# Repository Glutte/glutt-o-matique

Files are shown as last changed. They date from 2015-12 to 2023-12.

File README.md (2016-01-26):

Glutt-o-matique
===============

La nouvelle logique de la Glutte voit le jour ici.

On va utiliser un stm32f4-discovery. La collaboration
est gérée à l'aide d'un
[Trello](https://trello.com/b/NSvh8v81),
qui sert aussi d'aide-mémoire.

[La Glutte](http://www.glutte.ch)

L'essence de la glutt-o-matique
-------------------------------

Notre but  
est que la glutte  
fasse des tût-tûts.

Pour faire écho  
des beaux QSO  
depuis là-haut.

Donner comme retour  
entre chaque tour  
une lettre nuit et jour

Économiser l'energie  
pour la longue vie  
de la batterie.

Tout en annoncant  
le beau temps  
régulièrement.

Structure
---------

La machine d'états

Le PCB de prototype.

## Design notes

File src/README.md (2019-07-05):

Structure des dossiers source
=============================

- *bsp* pilotes et lib essentielle pour le STM32F4
- *common* sources utilisées dans la glutt-o-logique et le simulateur
- *FreeRTOS* sources de l'OS FreeRTOS pour le STM32F4
- *FreeRTOS-Sim-master* sources de la variante de FreeRTOS pour le simulateur
- *glutt-o-logique* code applicatif spécifique au STM32F4
- *simulator* code applicatif spécifique au simulateur y.c. interface graphique
- *temperature* code d'exemple, pour illustrer l'utilisation des entrées analogiques du STM32

Compiler le Simulateur
======================

Le simulateur de glutt-o-matique 3000 permet de tester le fonctionnement de la
logique sur un PC sans matériel spécial. Il faut un PC sous linux avec les librairies
X11, GL, GLU et pulseaudio, et faire

    cd simulator
    make
    ./FreeRTOS-Sim

Compiler le projet STM32
========================

Il faut un compilateur pour arm-none-eabi-, qui doit être dans le $PATH. Il
faut openocd pour FLASHer le STM32F4-DISCOVERY.

    cd glutt-o-logique
    make
    make deploy

Debug avec OpenOCD et GDB
=========================

    openocd -f /usr/share/openocd/scripts/board/stm32f4discovery.cfg  -c init -c reset

    arm-none-eabi-gdb bin/outp.elf
    target extended-remote localhost:3333
    monitor reset halt
    load
    continue

Debug simulateur avec GDB
=========================

    handle SIGUSR1 nostop noignore noprint
    handle SIG34 nostop noignore noprint

Analyse statique avec clang
===========================

Dans le simulateur scan-build tout seul fonctionne, mais dans glutt-o-logique/ il faut

    scan-build --use-cc=arm-none-eabi-gcc --analyzer-target=arm-none-eabi make ARCH=arm CROSS_COMPILE=arm-none-eabi-

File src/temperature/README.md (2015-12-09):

An example program that tries to read the
current temperature on the STM32F4DISCOVERY.

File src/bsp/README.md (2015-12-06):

This folder contains all files necessary to compile for the
STM32F4DISCOVERY board

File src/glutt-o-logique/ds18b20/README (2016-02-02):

This folder contains a library to access Dallas 1-wire temperature sensors.

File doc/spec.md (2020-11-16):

##Généralités

En mode secours, la glutt-o-matique doit être entièrement désactivée. Cela est
garanti en connectant le signal `SECOURS` sur l'entrée `RESET` du
microcontrôleur.

##Limites de tension pour QRP

Avec hysterèse:

 - en dessous de 12V5, passer en QRP
 - en dessus de 13V, passer en QRO

##Lettres CW

 * K : tout va bien (priorité 0)
 * G : relais en petite puissance (priorité 2)
 * U : RX trop haut en référence à 145'125 MHz (priorité 3)
 * D : RX trop bas 145'125 MHz (priorité 3)
 * S : mode SSTV (sans filtre 1725 Hz, priorité 1)
 * R : ROS sur antenne (priorité 4)

##Première phase : ouverture du relais
 * 1750 Hz pendant 200 ms, puis après relâchement de la porteuse :
 * TX ON, -> pause de 200ms, puis :
 * K,G,U,D,R (selon la situation du moment present du relais)

##Ensuite :

 * Pas de QSO, -> TX OFF après 6 s -> impossible de réentendre K, G, U, D, R pendant 15 s. Réouverture possible cependant du relais, pendant ce laps de temps de 15 s.
 * QSO -> le relais compte le temps d’un utilisateur, si plus de 5 min avec le même utilisateur, alors anti-bavard -> modulation OFF, et texte CW : HI HI, puis stop relais pendant 10 s, réouverture impossible avant 10 s
 * QSO normal de moins de 5 min. -> si plus d’action de PTT, fermeture du relais après 5 s, sans texte CW, puis idem :
 * QSO normal dépassant 5 min ->  texte CW : *73*, puis fermeture.
 * QSO normal dépassant 10 min ->  texte CW : *HB9G*, puis fermeture.
 * QSO normal dépassant 15 min ou plus -> texte CW au hasard, soit *HB9G JN36BG* ou *HB9G 1628 M*, puis fermeture

##Relais stand-by :
 * Pendant toutes les minutes que le relais n’est pas utilisé, après 20 minutes de silence consécutif, il TX une balise, au hasard, soit : *HB9G*, ou *HB9G JN36BK*, ou *HB9G 1628 M*, ou *HB9G JN36BK 1628 M*. Pendant ces balises, si un utilisateur utilise son PTT, il peut utiliser le relais comme si il avait fait un 1750 Hz, le relais réagit comme une ouverture normale.
 * Timer de balise : Commence à compter lors de l'arrêt du relais. Si qso, arrêt de timer avec mémoire du temps écoulé, puis reprise du comptage dès la fin du qso. Si qso plus long que 10 min. -> timer RAZ. Si timer = 20 min TX balise, puis RAZ
 * Si le relais en QRP ou ROS, plus aucune de ces balise sont en fonction
 * Une fois entrée en mode ROS, seul une coupure de courant ou un passage en SECOURS peut faire passer en mode normal.

##Toutes les heures paires :

Le relais, seulement s'il n'y a pas de QSO en cours, (sinon il attend la fin du QSO), dès qu’il a la possibilité, il prend la main sur toutes autres activités possible, (modulation off, et 1750Hz) puis il TX une balise.

A partir d'octobre 2020:

*HB9G JN36BK U 13V5  1650 AH + T 12  73*

Tendance: + - ou = selon l'évolution de la capacité en Ah. T par pas de 1 degré C. *73* si éolienne dans le vent, *SK*
si repliée.

En QRP, *HB9G U 12V5  1010 AH  T 12  73*

Jusqu'en octobre 2020:

*HB9G JN36BK 1628 M U 13V5* (un pas de 0,5V est suffisant) puis la tendance à la charge ou décharge ou égale (representés par +/-/=), *T* (température) par pas de 2 degrés, puis *73* si la queue de l’éolienne est dans le vent, ou *SK* si elle est repliée.

Ou, si le relais en en QRP, ou ROS, alors :

*HB9G U 12V5 73* ou *SK*

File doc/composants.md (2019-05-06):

Quelques références de composants utilisées pour la glutt-o-matique

 - STM32DISCOVERY | ST Microelectronics |
 - Perfboard | Twin Industries 8100-45 |
 - Connecteur 12V | LEMO EGG.0B.302.CLL |
 - Connecteur DB25 filtré | FDB-25PTI2/1-LF |

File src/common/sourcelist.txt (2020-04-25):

GPIO/analog.c
GPIO/usart.c
GPIO/temperature.c
GPIO/batterycharge.c
GPS/gps.c
GPS/minmea.c
Core/common.c
Core/fsm.c
Core/stats.c
Core/main.c
Audio/cw.c
Audio/audio.c
Audio/audio_in.c
Audio/tone.c

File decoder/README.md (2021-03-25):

Introduction
------------

This folder contains a set of scripts that can be used to automatically decode the PSK125 beacon at 22:00

The `analyse_capture.grc` was designed with GNURadio 3.7, but later the python file was
manually ported to GNURadio 3.8, because the [MPSK receiver block was deprecated](https://github.com/gnuradio/gnuradio/issues/1083)

Dependencies
------------

* Python 3
* GNURadio 3.8
* An SDR device and a suitable I/Q capture tool

Principle of operation
----------------------

1. Capture I/Q data, in u8 format, at 20148ksps, centered on 145.700MHz, into a file called `iq.raw`
1. Demodulate FM and PSK using the GNURadio flowgraph `analyse_capture.grc`. It will write a file called `psk125.bit`
1. Run the `varidecode.py` script, which will read `psk125.bit` and write `psk125.txt` with decoded beacon data

Example for RTLSDR: `rtl_sdr -f 145700000 -n 204800000 iq.raw` will capture 100 seconds worth of IQ data.

References
----------

https://sdradventure.wordpress.com/2011/10/15/gnuradio-psk31-decoder-part-1/

https://sdradventure.wordpress.com/2011/10/15/gnuradio-psk31-decoder-part-2/

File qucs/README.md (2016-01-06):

Quelques simulations qucs pour la glutt-o-matique

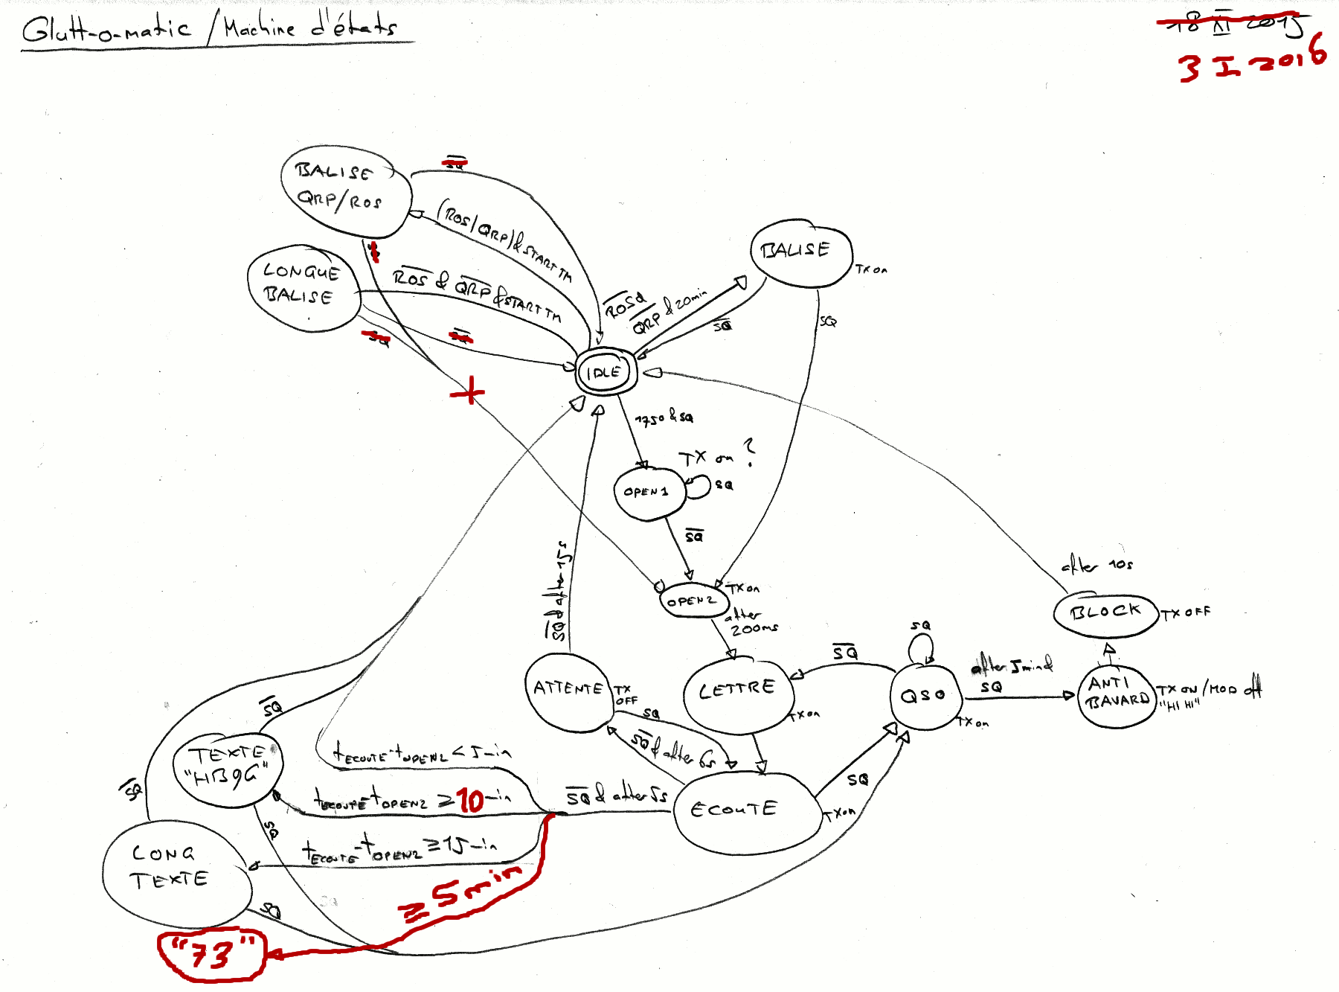
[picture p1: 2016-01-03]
doc/20160103-machine-etats.png

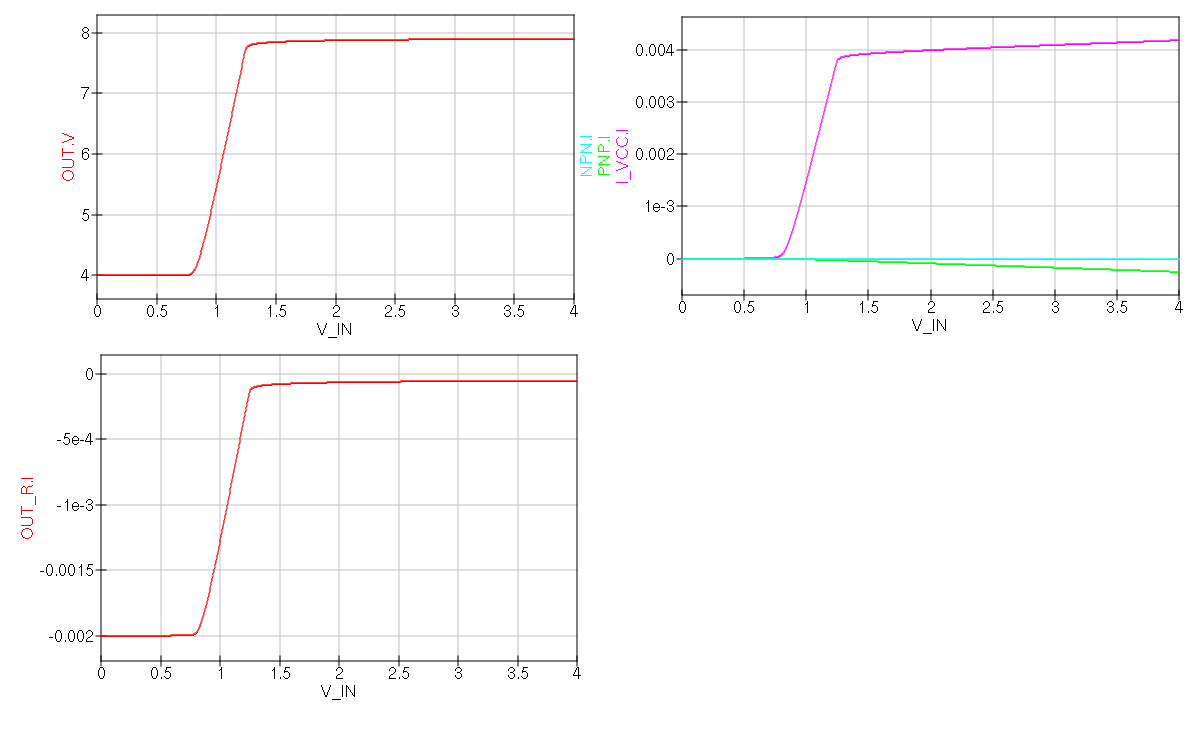
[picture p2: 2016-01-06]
qucs/levelshifter-graphs.png

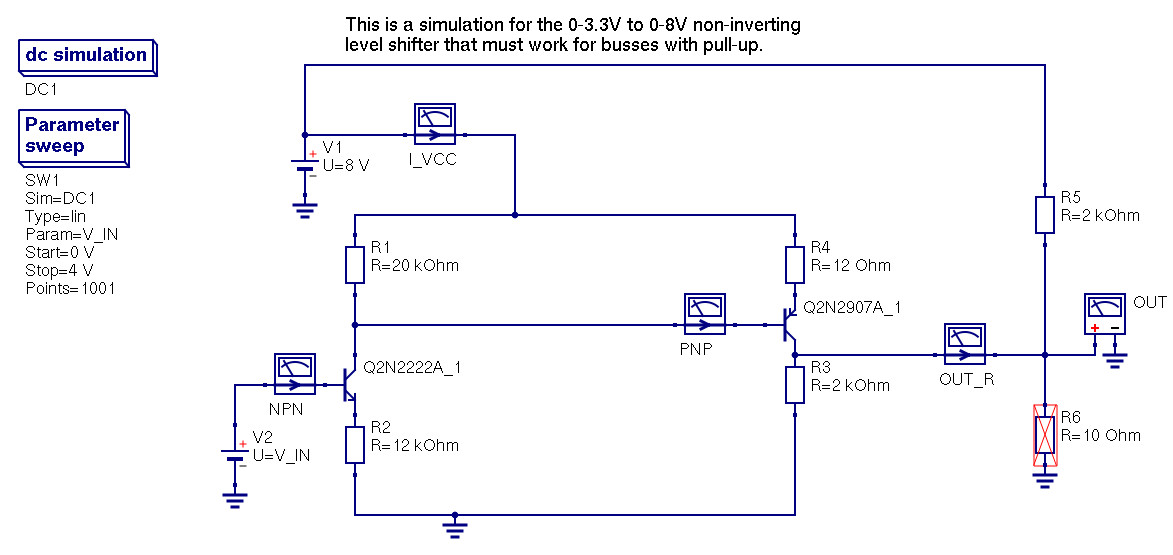
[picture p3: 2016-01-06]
qucs/levelshifter.png

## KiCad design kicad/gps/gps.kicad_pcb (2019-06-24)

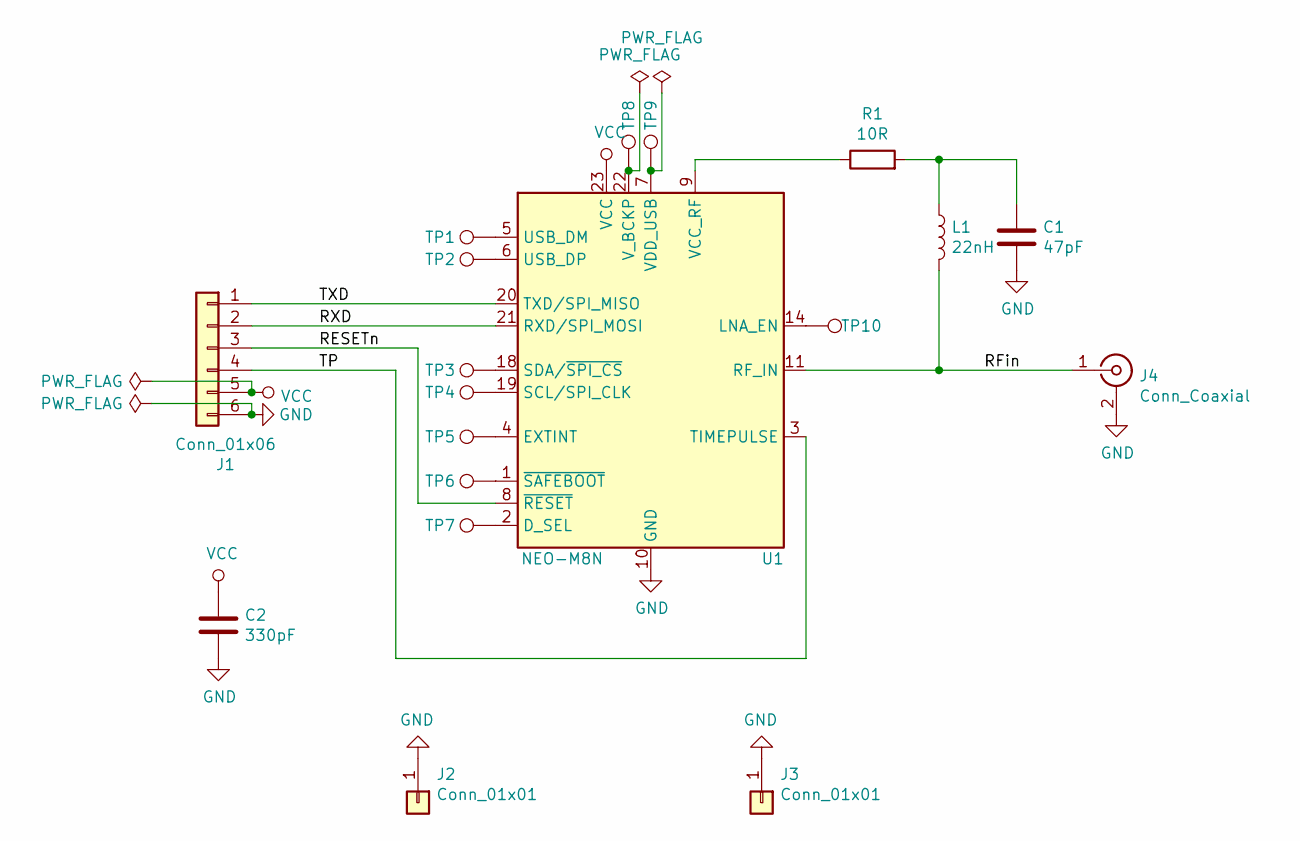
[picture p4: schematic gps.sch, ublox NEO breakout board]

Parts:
C1: 47pF; C_0603_1608Metric_Pad1.05x0.95mm_HandSolder
C2: 330pF; C_0805_2012Metric_Pad1.15x1.40mm_HandSolder
J1: Conn_01x06; PinHeader_1x06_P2.54mm_Vertical
J2, J3: Conn_01x01; PinHeader_1x01_P2.54mm_Vertical
J4: Conn_Coaxial; SMA_Samtec_SMA-J-P-H-ST-EM1_EdgeMount
L1: 22nH; L_0603_1608Metric_Pad1.05x0.95mm_HandSolder
R1: 10R; R_0603_1608Metric_Pad1.05x0.95mm_HandSolder
TP1: DM; TestPoint_Pad_1.0x1.0mm
TP2: DP; TestPoint_Pad_1.0x1.0mm
TP3: SDA; TestPoint_Pad_1.0x1.0mm
TP4: SCL; TestPoint_Pad_1.0x1.0mm
TP5: EXTINT; TestPoint_Pad_1.0x1.0mm
TP6: SB; TestPoint_Pad_1.0x1.0mm
TP7: DSEL; TestPoint_Pad_1.0x1.0mm
TP8: VBKP; TestPoint_Pad_1.0x1.0mm
TP9: VUSB; TestPoint_Pad_1.0x1.0mm
TP10: LNA; TestPoint_Pad_1.0x1.0mm
U1: NEO-M8N; ublox_NEO

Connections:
/RESETn: J1.3, U1.8 (~RESET)
/RFin: J4.1 (In), L1.2, U1.11 (RF_IN)
/RXD: J1.2, U1.21 (RXD/SPI_MOSI)
/TP: J1.4, U1.3 (TIMEPULSE)
/TXD: J1.1, U1.20 (TXD/SPI_MISO)
GND: C1.2, C2.2, J1.6, J2.1, J3.1, J4.2 (Ext), U1.10 (GND), U1.12 (GND), U1.13 (GND), U1.24 (GND)
unnamed: C1.1, L1.1, R1.2
unnamed: R1.1, U1.9 (VCC_RF)
unnamed: TP1.1, U1.5 (USB_DM)
unnamed: TP2.1, U1.6 (USB_DP)
unnamed: TP3.1, U1.18 (SDA/~SPI_CS)
unnamed: TP4.1, U1.19 (SCL/SPI_CLK)
unnamed: TP5.1, U1.4 (EXTINT)
unnamed: TP6.1, U1.1 (~SAFEBOOT)
unnamed: TP7.1, U1.2 (D_SEL)
unnamed: TP8.1, U1.22 (V_BCKP)
unnamed: TP9.1, U1.7 (VDD_USB)
unnamed: TP10.1, U1.14 (LNA_EN)
VCC: C2.1, J1.5, U1.23 (VCC)

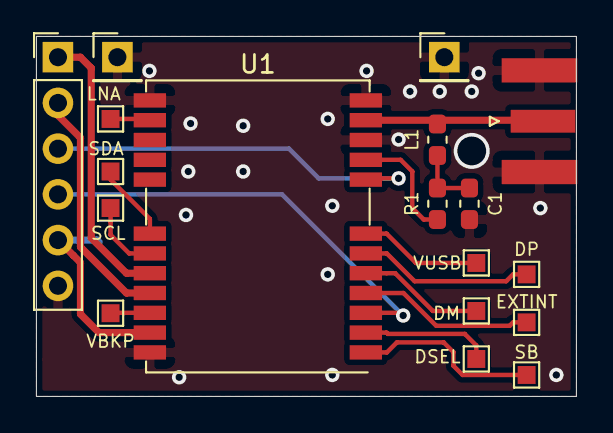
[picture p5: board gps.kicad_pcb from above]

Board: 2 copper layers, 30.0 x 20.0 mm, 19 parts (1 on the bottom side), 19 nets.

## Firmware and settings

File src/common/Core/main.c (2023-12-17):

/*
 * The MIT License (MIT)
 *
 * Copyright (c) 2020 Matthias P. Braendli, Maximilien Cuony
 *
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
 * THE SOFTWARE IS PROVIDED "AS IS", WITHOUT WARRANTY OF ANY KIND, EXPRESS OR
 * IMPLIED, INCLUDING BUT NOT LIMITED TO THE WARRANTIES OF MERCHANTABILITY,
 * FITNESS FOR A PARTICULAR PURPOSE AND NONINFRINGEMENT. IN NO EVENT SHALL THE
 * AUTHORS OR COPYRIGHT HOLDERS BE LIABLE FOR ANY CLAIM, DAMAGES OR OTHER
 * LIABILITY, WHETHER IN AN ACTION OF CONTRACT, TORT OR OTHERWISE, ARISING FROM,
 * OUT OF OR IN CONNECTION WITH THE SOFTWARE OR THE USE OR OTHER DEALINGS IN THE
 * SOFTWARE.
*/

#include <stdio.h>
#include <stdlib.h>
#include <stdint.h>
#include <string.h>
#include <math.h>

/* Kernel includes. */
#include "FreeRTOS.h"
#include "task.h"
#include "timers.h"
#include "semphr.h"

/* Includes */
#include "Audio/audio.h"
#include "Audio/audio_in.h"
#include "Audio/tone.h"
#include "Audio/cw.h"
#include "GPIO/pio.h"
#include "GPIO/i2c.h"
#include "GPS/gps.h"
#include "Core/fsm.h"
#include "Core/stats.h"
#include "Core/common.h"
#include "GPIO/usart.h"
#include "GPIO/batterycharge.h"
#include "Core/delay.h"
#include "GPIO/temperature.h"
#include "GPIO/leds.h"
#include "GPIO/analog.h"
#include "vc.h"

#ifdef SIMULATOR
extern int gui_in_tone_1750;
#endif

static void print_task_stats(void);

static int tm_trigger_button = 0;

static struct fsm_input_signals_t fsm_input;
static int hour_is_even = 0;

/* Threshold for SWR measurement */
const int swr_refl_threshold = 10; // mV

/* Saturating counter for SWR measurement
 *
 * Hysteresis:
 * If the counter reaches the max value, the
 * SWR Error is triggered.
 *
 * The error can only be cleared through
 * a full reset.
 */
#define SWR_ERROR_COUNTER_MAX 10
static int swr_error_counter = 0;
static int swr_error_flag = 0;

// Platform specific init function
void init(void);

// Tasks
static void detect_button_press(void *pvParameters);
static void exercise_fsm(void *pvParameters);
static void nf_analyse(void *pvParameters);
static void read_in_coulomb_counter(void *pvParameters);
static void gps_monit_task(void *pvParameters);
static void launcher_task(void *pvParameters);

// Audio callback function
static void audio_callback(void* context, int select_buffer);
// Debugging
static uint64_t timestamp_last_audio_callback = 0;

void vApplicationStackOverflowHook(TaskHandle_t, signed char *);

void vApplicationStackOverflowHook(TaskHandle_t __attribute__ ((unused)) xTask, signed char *pcTaskName) {
    usart_debug("TASK OVERFLOW %s\r\n", pcTaskName);
    trigger_fault(FAULT_SOURCE_TASK_OVERFLOW);
}

int main(void) {
    init();
    delay_init();
    usart_init();
    usart_debug("\r\n******* glutt-o-matique version %s *******\r\n", vc_get_version());

#ifndef SIMULATOR

    if (RCC_GetFlagStatus(RCC_FLAG_IWDGRST) != RESET)
    {
        usart_debug_puts("WARNING: A IWDG Reset occured!\r\n");
    }
    RCC_ClearFlag();

#endif

    TaskHandle_t task_handle;
    xTaskCreate(
            launcher_task,
            "Launcher",
            2*configMINIMAL_STACK_SIZE,
            (void*) NULL,
            tskIDLE_PRIORITY + 2UL,
            &task_handle);

    if (!task_handle) {
        trigger_fault(FAULT_SOURCE_MAIN);
    }

    vTaskStartScheduler();

    /* HALT */
    while(1);
}


// Launcher task is here to make sure the scheduler is
// already running when calling the init functions.
static void launcher_task(void __attribute__ ((unused))*pvParameters)
{
    usart_debug_puts("CW init\r\n");
    cw_psk_init(16000);

    usart_debug_puts("PIO init\r\n");
    pio_init();

    usart_debug_puts("Analog init\r\n");
    analog_init();

    usart_debug_puts("Batterycharge init\r\n");
    batterycharge_init();

    usart_debug_puts("I2C init\r\n");
    i2c_init();

    usart_debug_puts("common init\r\n");
    common_init();

    usart_debug_puts("GPS init\r\n");
    gps_init();

    usart_debug_puts("DS18B20 init\r\n");
    temperature_init();

    usart_debug_puts("TaskButton init\r\n");

    TaskHandle_t task_handle;
    xTaskCreate(
            detect_button_press,
            "TaskButton",
            4*configMINIMAL_STACK_SIZE,
            (void*) NULL,
            tskIDLE_PRIORITY + 2UL,
            &task_handle);

    if (!task_handle) {
        trigger_fault(FAULT_SOURCE_MAIN);
    }

    usart_debug_puts("TaskFSM init\r\n");

    xTaskCreate(
            exercise_fsm,
            "TaskFSM",
            4*configMINIMAL_STACK_SIZE,
            (void*) NULL,
            tskIDLE_PRIORITY + 2UL,
            &task_handle);

    if (!task_handle) {
        trigger_fault(FAULT_SOURCE_MAIN);
    }

    usart_debug_puts("TaskGPS init\r\n");

    xTaskCreate(
            gps_monit_task,
            "TaskGPSMonit",
            4*configMINIMAL_STACK_SIZE,
            (void*) NULL,
            tskIDLE_PRIORITY + 2UL,
            &task_handle);

    if (!task_handle) {
        trigger_fault(FAULT_SOURCE_MAIN);
    }

    usart_debug_puts("Audio init\r\n");
    audio_initialize(Audio16000HzSettings);

    usart_debug_puts("Audio set volume\r\n");
    audio_set_volume(210);

    usart_debug_puts("Audio set callback\r\n");
    audio_play_with_callback(audio_callback, NULL);

    usart_debug_puts("Tone init\r\n");
    tone_init();

    usart_debug_puts("Audio in init\r\n");
    audio_in_initialize();

    usart_debug_puts("TaskNF init\r\n");

    xTaskCreate(
            nf_analyse,
            "TaskNF",
            3*configMINIMAL_STACK_SIZE,
            (void*) NULL,
            tskIDLE_PRIORITY + 3UL,
            &task_handle);

    if (!task_handle) {
        trigger_fault(FAULT_SOURCE_MAIN);
    }

    usart_debug_puts("TaskCC init\r\n");

    xTaskCreate(
            read_in_coulomb_counter,
            "TaskCC",
            2*configMINIMAL_STACK_SIZE,
            (void*) NULL,
            tskIDLE_PRIORITY + 3UL,
            &task_handle);

    if (!task_handle) {
        trigger_fault(FAULT_SOURCE_MAIN);
    }

    usart_debug_puts("Init done.\r\n");

    int last_qrp_from_supply = 0;
    int send_audio_callback_warning = 0;

    int i = 0;

    while(1) {
        vTaskDelay(pdMS_TO_TICKS(1000));

        if (i == 0) {
            i = 1;
            leds_turn_on(LED_GREEN);

            print_task_stats();
        }
        else {
            i = 0;
            leds_turn_off(LED_GREEN);
        }

        struct fsm_output_signals_t fsm_out;
        fsm_get_outputs(&fsm_out);

        tone_detector_enable(fsm_out.require_tone_detector);

        if (fsm_out.tx_on) {
            int swr_fwd_mv, swr_refl_mv;
            if (analog_measure_swr(&swr_fwd_mv, &swr_refl_mv)) {
                if (swr_refl_mv > swr_refl_threshold) {
                    usart_debug("SWR meas %d mV\r\n", swr_refl_mv);
                    swr_error_counter++;
                }
                else {
                    swr_error_counter--;
                }

                if (swr_error_counter > SWR_ERROR_COUNTER_MAX) {
                    swr_error_counter = SWR_ERROR_COUNTER_MAX;
                    if (!swr_error_flag) {
                        usart_debug("Set SWR error\r\n");
                    }
                    swr_error_flag = 1;
                    pio_set_qrp(1);
                }
            }
        }
        else {
            if (swr_error_flag) {
                pio_set_qrp(1);
            }
            else {
                const int charge_qrp = batterycharge_too_low();

                if (charge_qrp != -1) {
                    if (charge_qrp != last_qrp_from_supply) {
                        usart_debug("QRP CC = %d\r\n", charge_qrp);
                        last_qrp_from_supply = charge_qrp;

                        pio_set_qrp(charge_qrp);
                    }
                }
                else {
                    /* Read the voltage when battery capacity is not available */
                    const int qrp_from_supply = analog_supply_too_low();
                    if (qrp_from_supply != last_qrp_from_supply) {
                        usart_debug("QRP U = %d\r\n", qrp_from_supply);
                        last_qrp_from_supply = qrp_from_supply;

                        pio_set_qrp(qrp_from_supply);
                    }
                }
            }
        }

        const int64_t delta = timestamp_now() - timestamp_last_audio_callback;
        if (delta > 1000) {
            if (send_audio_callback_warning == 0) {
                send_audio_callback_warning = 1;
                usart_debug("[HOHO] timestamp_last_audio_callback > 1000 : %d\r\n", delta);
            }
        }
        else {
            if (send_audio_callback_warning == 1) {
                send_audio_callback_warning = 0;
                usart_debug("[HOHO] Fix ? Now timestamp_last_audio_callback < 1000\r\n");
            }
        }
    }
}


static void detect_button_press(void __attribute__ ((unused))*pvParameters)
{
    int pin_high_count = 0;
    int last_pin_high_count = 0;
    const int pin_high_thresh = 10;
    while (1) {
        if (pio_read_button()) {
            if (pin_high_count < pin_high_thresh) {
                pin_high_count++;
            }
        }
        else {
            if (pin_high_count > 0) {
                pin_high_count--;
            }
        }

        vTaskDelay(pdMS_TO_TICKS(10)); /* Debounce Delay */

        if (pin_high_count == pin_high_thresh &&
                last_pin_high_count != pin_high_count) {
            tm_trigger_button = 1;
            usart_debug_puts("Bouton bleu\r\n");
        }
        else if (pin_high_count == 0 &&
                last_pin_high_count != pin_high_count) {
            tm_trigger_button = 0;
        }

        last_pin_high_count = pin_high_count;
    }
}

int only_zero_in_audio_buffer = 1;
int count_zero_audio_buffer = 0;

static void audio_callback(void __attribute__ ((unused))*context, int select_buffer) {
    static int16_t audio_buffer0[AUDIO_BUF_LEN];
    static int16_t audio_buffer1[AUDIO_BUF_LEN];
    int16_t *samples;

    if (select_buffer == 0) {
        samples = audio_buffer0;
        leds_turn_off(LED_RED);
    } else {
        samples = audio_buffer1;
        leds_turn_on(LED_RED);
    }

    size_t samples_len = cw_psk_fill_buffer(samples, AUDIO_BUF_LEN);

    if (samples_len == 0) {
        for (int i = 0; i < AUDIO_BUF_LEN; i++) {
            samples[i] = 0;
        }

        samples_len = AUDIO_BUF_LEN;

        if (count_zero_audio_buffer < 2) {
            count_zero_audio_buffer++;
        } else {
            only_zero_in_audio_buffer = 1;
        }
    } else {
        only_zero_in_audio_buffer = 0;
        count_zero_audio_buffer = 0;
    }

    if (!audio_provide_buffer_without_blocking(samples, samples_len)) {
        usart_debug("[HOHO] audio_provide_buffer_without_blocking returned False.\r\n");
    }

    timestamp_last_audio_callback = timestamp_now();
}

static struct tm gps_time;
static void gps_monit_task(void __attribute__ ((unused))*pvParameters) {

    /* There are two types of non GPS clocks: the DERIVED one which works if
     * GPS time was known at some point, and the free-running that only depends
     * on timestamp_now(). The free-running one is used to ensure 2h beacons are
     * transmitted even if GPS never gave us time. The DERIVED kicks in when GPS
     * fails after having output time information and tries to keep accurate absolute
     * time.
     */

    pio_set_gps_epps(1);

    int t_gps_print_latch = 0;
    int t_gps_hours_handeled = 0;
    uint64_t last_hour_timestamp = 0;

    uint64_t last_volt_and_temp_timestamp, last_hour_is_even_change_timestamp;
    last_volt_and_temp_timestamp = last_hour_is_even_change_timestamp = timestamp_now();

    int last_even = -1;

    while (1) {
        const uint64_t now = timestamp_now();

        struct tm time = {0};
        int time_valid = local_time(&time);
        int derived_mode = 0;

        if (time_valid) {
            if (time.tm_sec % 2) {
                pio_set_gps_epps(1);
            }
            else {
                pio_set_gps_epps(0);
            }

            derived_mode = 0;
        }
        else {
            time_valid = local_derived_time(&time);

            if (time_valid) {
                if (time.tm_sec % 4 >= 2) {
                    pio_set_gps_epps(1);
                }
                else {
                    pio_set_gps_epps(0);
                }

                derived_mode = 1;
            }
        }

        if (time_valid) {
            hour_is_even = (time.tm_hour + 1) % 2;

            if (last_even != hour_is_even) {
                last_even = hour_is_even;

                usart_debug("Even changed: %i %i %s\r\n", hour_is_even, time.tm_hour, derived_mode ? "DERIVED" : "GPS");
            }
        }
        else if (last_hour_is_even_change_timestamp + (2 * 3600 * 1000) < now) {
            hour_is_even = (hour_is_even + 1) % 2;
            last_even = hour_is_even;

            usart_debug("Even changed: %i %i FREE-RUNNING\r\n", hour_is_even, time.tm_hour);
            last_hour_is_even_change_timestamp = now;
        }

        if (last_volt_and_temp_timestamp + 20000 < now) {
            const float u_bat = analog_measure_12v();
            const uint32_t capacity_bat = batterycharge_retrieve_last_capacity();

            usart_debug("ALIM %d mV\r\n", (int)roundf(1000.0f * u_bat));

            stats_voltage(u_bat);
            if (time_valid && time.tm_min == 0) {
                stats_battery_at_full_hour(time.tm_hour, u_bat, capacity_bat);
            }

            float temp = 0;
            if (temperature_get(&temp)) {
                stats_temp(temp);

                const char *sign = "";
                if (temp < 0) {
                    sign = "-";
                    temp = -temp;
                }

                usart_debug("TEMP %s%d.%02d\r\n", sign, (int)temp, (int)(temp * 100.0f - (int)(temp) * 100.0f));
            }
            else {
                usart_debug("TEMP invalid\r\n");
            }

            last_volt_and_temp_timestamp = now;
        }

        int num_sv_used = 0;
        gps_utctime(&gps_time, &num_sv_used);

        if (time.tm_sec % 30 == 0 && t_gps_print_latch == 0) {
            usart_debug("T_GPS %04d-%02d-%02d %02d:%02d:%02d %d SV tracked\r\n",
                gps_time.tm_year + 1900, gps_time.tm_mon + 1, gps_time.tm_mday,
                gps_time.tm_hour, gps_time.tm_min, gps_time.tm_sec,
                num_sv_used);

            stats_num_gnss_sv(num_sv_used);

            char *mode = "";

            if (derived_mode) {
                mode = "Derived";
            }
            else {
                mode = "GPS";
            }

            usart_debug("TIME  %04d-%02d-%02d %02d:%02d:%02d [%s]\r\n",
                time.tm_year + 1900,
                time.tm_mon + 1, time.tm_mday,
                time.tm_hour, time.tm_min, time.tm_sec,
                mode);

            t_gps_print_latch = 1;
        }

        if (time.tm_sec % 30 > 0) {
            t_gps_print_latch = 0;
        }

        if (time_valid && derived_mode == 0 && gps_time.tm_sec == 0 && gps_time.tm_min == 0 && t_gps_hours_handeled == 0) {
            if (last_hour_timestamp == 0) {
                usart_debug("DERIV INIT TS=%lld\r\n", now);
            }
            else {
                usart_debug("DERIV TS=%lld Excepted=%lld Delta=%lld\r\n",
                    now,
                    last_hour_timestamp + 3600000,
                    last_hour_timestamp + 3600000 - now
                );
            }

            last_hour_timestamp = now;

            t_gps_hours_handeled = 1;
        }

        if (gps_time.tm_sec != 0) {
            t_gps_hours_handeled = 0;
        }

        vTaskDelay(pdMS_TO_TICKS(100));

        // Reload watchdog
#ifndef SIMULATOR
        IWDG_ReloadCounter();
#endif
    }
}

static void exercise_fsm(void __attribute__ ((unused))*pvParameters)
{
    fsm_init();

    int cw_last_trigger = 0;
    int last_tm_trigger_button = 0;

    int last_tx_on = 0;
    int last_sq = 0;
    int last_qrp = 0;
    int last_cw_done = 0;
    int last_discrim_d = 0;
    int last_discrim_u = 0;
    int last_wind_generator_ok = 0;

    uint64_t last_qrp_stats_updated = timestamp_now();

    fsm_input.temp = 15;
    fsm_input.swr_high = 0;
    fsm_input.fax_mode = 0;
    fsm_input.wind_generator_ok = 1;
    fsm_input.send_stats = 0;
    fsm_input.bonne_annee = 0;

    while (1) {
        vTaskDelay(pdMS_TO_TICKS(10));

        pio_set_fsm_signals(&fsm_input);

        const uint64_t now = timestamp_now();

        // QRP/QRO doesn't change too often, updating every 10s is good enough
        if (last_qrp_stats_updated + 10000 < now) {
            stats_qrp(fsm_input.qrp);
            last_qrp_stats_updated = now;
        }

        if (last_sq != fsm_input.sq) {
            last_sq = fsm_input.sq;
            usart_debug("In SQ %d\r\n", last_sq);
        }
        if (last_qrp != fsm_input.qrp) {
            last_qrp = fsm_input.qrp;
            usart_debug("In QRP %d\r\n", last_qrp);
        }
        if (last_discrim_d != fsm_input.discrim_d) {
            last_discrim_d = fsm_input.discrim_d;
            usart_debug("In D %d\r\n", last_discrim_d);
        }
        if (last_discrim_u != fsm_input.discrim_u) {
            last_discrim_u = fsm_input.discrim_u;
            usart_debug("In U %d\r\n", last_discrim_u);
        }
        if (last_wind_generator_ok != fsm_input.wind_generator_ok) {
            last_wind_generator_ok = fsm_input.wind_generator_ok;
            stats_wind_generator_moved();
            usart_debug("In eolienne %s\r\n", last_wind_generator_ok ? "vent" : "replie");
        }

        const int cw_psk_done = !cw_psk_busy();
        const int cw_done = cw_psk_done && only_zero_in_audio_buffer;

        // Set the done flag to 1 only once, when cw_done switches from 0 to 1
        if (last_cw_done != cw_done) {
            usart_debug("In cw_done change %d %d\r\n", cw_done, only_zero_in_audio_buffer);

            if (cw_done) {
                fsm_input.cw_psk_done = cw_done;
                leds_turn_off(LED_ORANGE);
            }

            last_cw_done = cw_done;
        }
        else {
            fsm_input.cw_psk_done = 0;
        }


        const int current_tone_1750_status = tone_1750_status();
#ifdef SIMULATOR
        gui_in_tone_1750 = current_tone_1750_status;
#endif
        fsm_input.det_1750 = current_tone_1750_status;
        pio_set_det_1750(current_tone_1750_status);

        fsm_input.long_1750 = tone_1750_for_5_seconds();

        // TODO implement a DTMF controlled state machine for setting SQ2
        pio_set_sq2(0);

        fsm_input.fax_mode = tone_fax_status();
        fsm_input.swr_high = swr_error_flag;
        fsm_input.hour_is_even = hour_is_even;

        struct tm time = {0};
        int time_valid = local_time(&time);
        if (!time_valid) {
            time_valid = local_derived_time(&time);
        }

        if (time_valid) {
            fsm_input.send_stats = (time.tm_hour == 22) ? 1 : 0;
            fsm_input.bonne_annee = (gps_time.tm_mon == 0 && gps_time.tm_mday <= 5);
        }
        else {
            fsm_input.send_stats = 0;
            fsm_input.bonne_annee = 0;
        }

        fsm_update_inputs(&fsm_input);

        if (tm_trigger_button == 1 && last_tm_trigger_button == 0) {
            fsm_update_inputs(&fsm_input);
            fsm_balise_force();
        }
        last_tm_trigger_button = tm_trigger_button;

        fsm_update();
        fsm_balise_update();
        const int disable_1750_filter = fsm_sstv_update();
        pio_set_fax(disable_1750_filter);

        struct fsm_output_signals_t fsm_out;
        fsm_get_outputs(&fsm_out);

        pio_set_tx(fsm_out.tx_on);
        if (fsm_out.tx_on != last_tx_on) {
            stats_tx_switched(fsm_out.tx_on);
            last_tx_on = fsm_out.tx_on;
        }
        pio_set_mod_off(!fsm_out.modulation);

        // Add message to CW generator only on rising edge of trigger
        if (fsm_out.cw_psk_trigger && !cw_last_trigger && fsm_out.msg != NULL) {
            const int success = cw_psk_push_message(fsm_out.msg, fsm_out.cw_dit_duration, fsm_out.msg_frequency);
            if (!success) {
                usart_debug_puts("cw_psk_push_message failed");
            }

            leds_turn_on(LED_ORANGE);
        }
        cw_last_trigger = fsm_out.cw_psk_trigger;
    }
}

const int BLUE_LED_INTVL = 4;
static int blue_led_phase = 0;
static void nf_analyse(void __attribute__ ((unused))*pvParameters)
{
    while (1) {
        if (blue_led_phase == 0) {
            leds_turn_on(LED_BLUE);
        }
        else if (blue_led_phase == BLUE_LED_INTVL) {
            leds_turn_off(LED_BLUE);
        }

        blue_led_phase++;

        if (blue_led_phase >= BLUE_LED_INTVL * 2) {
            blue_led_phase = 0;
        }

        tone_do_analysis();
    }
}

static char ccounter_msg[MAX_CCOUNTER_SENTENCE_LEN];
static void read_in_coulomb_counter(void __attribute__ ((unused))*pvParameters)
{
    while (1) {
        int ok = usart_get_ccounter_msg(ccounter_msg); // times out after 2s
        if (ok) {
            size_t len = strlen(ccounter_msg);
            /* Ignore if \n follows \r or not, as that should never happen, and in any case
             * we don't want to send the \r or whatever could come after.
             */
            if (len > 2 && ccounter_msg[len-2] == '\r') {
                ccounter_msg[len-2] = '\0';
            }

            batterycharge_push_message(ccounter_msg);
            usart_debug_puts_header("CC: ", ccounter_msg);
        }
    }
}

#if configGENERATE_RUN_TIME_STATS
#include "stm32f4xx_conf.h"
#include "stm32f4xx_tim.h"
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

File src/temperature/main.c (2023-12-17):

#include <stdio.h>
#include <stdlib.h>
#include <stdint.h>
#include <math.h>
#include "stm32f4xx_conf.h"

/* Kernel includes. */
#include "FreeRTOS.h"
#include "task.h"
#include "timers.h"
#include "semphr.h"

#include "temperature.h"
#include "i2c.h"
#include "bmp085.h"

#include "debug.h"


ADC_InitTypeDef ADC_InitStruct;

ADC_CommonInitTypeDef ADC_CommonInitStruct;


// Private variables
volatile uint32_t time_var1, time_var2;

// Private function prototypes
void init();

// Tasks
static void detect_button_press(void *pvParameters);


void vApplicationStackOverflowHook( TaskHandle_t xTask,
                                    signed char *pcTaskName )
{
    while (1) {};
}
extern void initialise_monitor_handles(void);

// Launcher task is here to make sure the scheduler is
// already running when calling the init functions.
static void launcher_task(void __attribute__ ((unused))*pvParameters)
{
    init();

    xTaskCreate(
            detect_button_press,
            "TaskButton",
            4*configMINIMAL_STACK_SIZE,
            (void*) NULL,
            tskIDLE_PRIORITY + 2UL,
            NULL);

    while (1) {
        vTaskDelay(pdMS_TO_TICKS(1000));

        GPIO_SetBits(GPIOD, GPIO_Pin_13);
        temperature_update();
        GPIO_ResetBits(GPIOD, GPIO_Pin_13);
        taskYIELD();
    }
}

int main(void) {
    TaskHandle_t task_handle;
    xTaskCreate(
            launcher_task,
            "Launcher",
            2*configMINIMAL_STACK_SIZE,
            (void*) NULL,
            tskIDLE_PRIORITY + 2UL,
            &task_handle);

    /* Start the RTOS Scheduler */
    vTaskStartScheduler();

    /* HALT */
    while(1);
}

static void detect_button_press(void *pvParameters)
{
    GPIO_SetBits(GPIOD, GPIO_Pin_12);

    while (1) {
        if (GPIO_ReadInputDataBit(GPIOA,GPIO_Pin_0)>0) {

            while (GPIO_ReadInputDataBit(GPIOA,GPIO_Pin_0) > 0) {
                vTaskDelay(pdMS_TO_TICKS(100)); /* Button Debounce Delay */
            }

            GPIO_ResetBits(GPIOD, GPIO_Pin_12);
            GPIO_SetBits(GPIOD, GPIO_Pin_15);
            debug_print("Le jeu. Temp is: ");

            char t[32];
            // For debugging purposes only. snprinf has issues with %f
            float temp = 0;
            int temp_valid = temperature_get(&temp);
            snprintf(t, 32, "%d.%02d", (int)temp, (int)(temp * 100.0 - (int)temp * 100.0));
            debug_print(t);

            int32_t pressure = 0;
            int32_t temperature = 0;
            int success = bmp085_get_temp_pressure(&temperature, &pressure);
            snprintf(t, 32, " (%d) P=%ld, T=%ld", success, pressure, temperature);
            debug_print(t);
            debug_print("\n");

            GPIO_ResetBits(GPIOD, GPIO_Pin_15);
            GPIO_SetBits(GPIOD, GPIO_Pin_12);

            while (GPIO_ReadInputDataBit(GPIOA,GPIO_Pin_0) == 0) {
                vTaskDelay(pdMS_TO_TICKS(100)); /* Button Debounce Delay */
            }
        }
        taskYIELD();
    }
}

void init() {
    GPIO_InitTypeDef  GPIO_InitStructure;
    USART_InitTypeDef USART_InitStructure;
    // ---------- SysTick timer -------- //
    if (SysTick_Config(SystemCoreClock / 1000)) {
        // Capture error
        while (1){};
    }

    // Enable full access to FPU (Should be done automatically in system_stm32f4xx.c):
    //SCB->CPACR |= ((3UL << 10*2)|(3UL << 11*2));  // set CP10 and CP11 Full Access

    // GPIOD Periph clock enable
    RCC_AHB1PeriphClockCmd(RCC_AHB1Periph_GPIOD, ENABLE);

    // Configure PD12, PD13, PD14 and PD15 in output pushpull mode
    GPIO_InitStructure.GPIO_Pin = GPIO_Pin_12 | GPIO_Pin_13| GPIO_Pin_14| GPIO_Pin_15;
    GPIO_InitStructure.GPIO_Mode = GPIO_Mode_OUT;
    GPIO_InitStructure.GPIO_OType = GPIO_OType_PP;
    GPIO_InitStructure.GPIO_Speed = GPIO_Speed_100MHz;
    GPIO_InitStructure.GPIO_PuPd = GPIO_PuPd_NOPULL;
    GPIO_Init(GPIOD, &GPIO_InitStructure);

    // Init PushButton
    GPIO_InitStructure.GPIO_Mode = GPIO_Mode_IN;
    GPIO_InitStructure.GPIO_Pin =  GPIO_Pin_0;
    GPIO_InitStructure.GPIO_PuPd = GPIO_PuPd_NOPULL;
    GPIO_InitStructure.GPIO_Speed = GPIO_Speed_100MHz;
    GPIO_InitStructure.GPIO_OType = GPIO_OType_PP;
    GPIO_Init(GPIOA, &GPIO_InitStructure);


    // ------ UART ------ //

    // Clock
    RCC_APB1PeriphClockCmd(RCC_APB1Periph_USART2, ENABLE);
    RCC_AHB1PeriphClockCmd(RCC_AHB1Periph_GPIOA, ENABLE);

    // IO
    GPIO_InitStructure.GPIO_Pin = GPIO_Pin_5 | GPIO_Pin_6;
    GPIO_InitStructure.GPIO_Speed = GPIO_Speed_100MHz;
    GPIO_InitStructure.GPIO_Mode = GPIO_Mode_AF;
    GPIO_InitStructure.GPIO_OType = GPIO_OType_PP;
    GPIO_InitStructure.GPIO_PuPd = GPIO_PuPd_UP;
    GPIO_Init(GPIOD, &GPIO_InitStructure);

    GPIO_PinAFConfig(GPIOD, GPIO_PinSource5, GPIO_AF_USART1);
    GPIO_PinAFConfig(GPIOD, GPIO_PinSource6, GPIO_AF_USART1);

    // Conf
    USART_InitStructure.USART_BaudRate = 115200;
    USART_InitStructure.USART_WordLength = USART_WordLength_8b;
    USART_InitStructure.USART_StopBits = USART_StopBits_1;
    USART_InitStructure.USART_Parity = USART_Parity_No;
    USART_InitStructure.USART_HardwareFlowControl = USART_HardwareFlowControl_None;
    USART_InitStructure.USART_Mode = USART_Mode_Tx | USART_Mode_Rx;
    USART_Init(USART2, &USART_InitStructure);

    // Enable
    USART_Cmd(USART2, ENABLE);


    // Temperature using ADC
    
    // Enable ADC clock
    RCC_APB2PeriphClockCmd(RCC_APB2Periph_ADC1, ENABLE);

    // Init ADC
    ADC_CommonInitStruct.ADC_Mode = ADC_Mode_Independent;
    ADC_CommonInitStruct.ADC_Prescaler = ADC_Prescaler_Div8;
    ADC_CommonInitStruct.ADC_DMAAccessMode = ADC_DMAAccessMode_Disabled;
    ADC_CommonInitStruct.ADC_TwoSamplingDelay = ADC_TwoSamplingDelay_5Cycles;
    ADC_CommonInit(&ADC_CommonInitStruct);

    ADC_InitStruct.ADC_Resolution = ADC_Resolution_12b;
    ADC_InitStruct.ADC_ScanConvMode = DISABLE;
    ADC_InitStruct.ADC_ContinuousConvMode = ENABLE;
    ADC_InitStruct.ADC_ExternalTrigConvEdge = ADC_ExternalTrigConvEdge_None;
    ADC_InitStruct.ADC_ExternalTrigConv = ADC_ExternalTrigConv_T1_CC1;
    ADC_InitStruct.ADC_DataAlign = ADC_DataAlign_Right;
    ADC_InitStruct.ADC_NbrOfConversion = 1;
    ADC_Init(ADC1, &ADC_InitStruct);

    // Configure ADC1 to use temperture sensor
    ADC_RegularChannelConfig(ADC1, ADC_Channel_TempSensor, 1, ADC_SampleTime_144Cycles);

    // Enable temperature sensor
    ADC_TempSensorVrefintCmd(ENABLE);

    // Enable ADC
    ADC_Cmd(ADC1, ENABLE);

    debug_print("Init ADC done\n");

    // Enable I2C
    i2c_init();
    if (! bmp085_init() ) {
        debug_print("Init BMP085 fail\n");
    }
    else {
        debug_print("Init BMP085 ok\n");
    }
}

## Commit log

2015-11-02 Add schematics
2015-12-06 Fix interrupt prio, add tone test
    [audio.c, main.c]
2015-12-07 Fix stack overflow, it resembles CW now
    [main.c]
2015-12-09 Temperature measurements
2015-12-19 Move i2c init to separate file, use library
2015-12-19 Fix I2C for GPS, needs timeout handling
    [audio.c, common.h, i2c.c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]
2015-12-19 Add i2c timeouts
2015-12-20 Properly reset I2C bus in case of error
    [i2c.c]
2015-12-20 Give names to board leds
2015-12-20 Enable pullups on I2C
2015-12-20 Fix I2C SW reset
    [i2c.c]
2015-12-28 GPS: Replace UBX over I2C to NMEA over UART
    [main.c, usart.c]
2016-01-06 Add qucs sim for level shifter
    [levelshifter.sch]
2016-01-17 perfboard: DB25 connector and inverting level shifter
2016-01-17 Perfboard: add mini-jack connector
2016-01-17 Replace zener by resistor dividers in perfboard
2016-01-24 Move debug UART to USART2, audio broken
    [audio.c, main.c, usart.c]
2016-01-24 Nicer debug prints
2016-01-24 Fix i2c GPIOB init
    [i2c.c]
2016-01-24 Use GPIO functions in audio driver
2016-01-24 Save power by disabling audio when audio is not requiered to bip
2016-01-25 Perfboard: move stm32, add MAX232
2016-01-26 Update PIO usage for new board
2016-02-02 Enable printout in hard fault handler
2016-02-02 Add schematic
2016-02-02 Make things on schematic smaller
2016-02-04 Add DCDC to schematic and perfboard
2016-02-04 Add LM324 to perfboard, update schematic
2016-02-07 Add power bus to perfboard
2016-02-07 Use power bus for opamps
2016-02-21 Reorder DB25 pin header
2016-03-15 Move some resistors
2016-03-15 Fix base board size
2016-04-10 Change resistor orientation next to 2N2222
2016-04-17 Remove orange led from pio.txt
2016-04-18 Disable task switching when using UART
2016-05-13 schematic: add opamp gain and protection
2016-05-14 Schematic: 22k instead of 20k divider
2016-05-14 Schematic: Update date
2016-05-14 perfboard: update opamp circuit
2016-05-30 Add more USART debug prints
2016-06-02 Simulator: UART, Leds, begining of GPS
2016-06-03 Travail de train GPS
2016-06-05 Fix timestamp and fsm date
    [fsm.c]
2016-06-05 Restructure stm32 project
2016-06-05 Fix includes in source files
    [audio.c, fsm.c, leds.c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]
2016-06-05 Fix includes, add headers, add CW usart print
    [audio.c, fsm.c]
2016-06-05 Fix USART concurrency, create common usart object
    [fsm.c, usart.c]
2016-06-05 Remove unused function threadscheduler
2016-06-05 Make objects for common/ leds temperature
2016-06-05 Fix common_timestamp on stm32
2016-06-05 Fix GND on perfboard DB25
2016-06-05 Enable audio depending on TX_ON
    This removes the glitch issue
    [main.c]
2016-06-06 Fix warnings, add more warnings flags, normalize makefiles
    [audio.c, audio.h, common.h]
2016-06-06 Wrong order of leds
2016-06-11 i2c: prefer pdMS_TO_TICKS macro
2016-06-11 Rework i2c lockup handling
    [audio.c, audio.h, i2c.c]
2016-06-11 Fix missing prototype warning.
    It's a bit stupid if you ask me...
    [main.c]
2016-06-12 fix variable name and remove useless sqrtf call
    [analog_input.c]
2016-06-12 Improve supply voltage measurement, WIP
2016-06-12 Fix analog supply voltage readout
    [analog_input.c, main.c, usart.c]
2016-06-12 Transmit voltage and temperature in beacons
2016-06-12 Update schematic and layout
2016-06-12 Add input voltage
2016-06-12 On ne peux pas redimensionner la fenêtre "FSM" :-(
2016-06-13 Update SECOURS on schematic and perfboard
2016-06-14 Try to fix truncatered CW
    [main.c]
2016-06-15 Update short beacon based on specs
    [fsm.c]
2016-06-20 Replace LED_BLUE by GPS EPPS
    [main.c, pio.c, pio.h]
2016-06-23 Update schematics and perfboard
    Add audio filter, Correct SWR measurement, Zener voltages, GPS EPPS output,
    Cosmetics
2016-06-24 Fix opamp connection on schematic
2016-06-24 Add code to read SWR analog voltages
2016-06-25 Added new GPS led
2016-07-10 Add GPS SMA connector to back plate
2016-07-10 Add REPLIE inverter and voltage shifter
2016-07-10 Invert REPLIE signal in software
    [pio.c, pio.h]
2016-07-10 Add reflected power handling with fixed threshold
    [analog_input.c, main.c]
2016-07-14 Add db25 connector schematic
2016-07-14 Update schematic, make V-1wire fat
2016-07-18 FSM: Remove TX_ON from OPEN1
    This makes it impossible to get stuck with TX_ON if SQ never goes low.
    Transition from BALISE_OPEN directly goes to OPEN2, regardless of SQ, making
    a seamless switch from beacon-mode to repeater-mode for the users.
    [fsm.c]
2016-07-18 Fix ATTENTE, require additional timing check
    [fsm.c]
2016-08-20 Remove runtime reset of SWR error
    Only a full system reset can clear the high SWR error.
    [main.c]
2016-08-20 Remove temperature print on button press
2016-08-29 Remove RAW Meas debug printf
2016-09-02 Increase component sizes on schematic
2016-09-03 FSM: switch to OPEN1 only with 1750
2016-09-04 Fix D and U transmission
    [pio.c]
2016-09-04 Rework balise trigger and fix ECOUTE lockup
    [fsm.c, main.c]
2016-09-04 Fix override of hour evenness
    [main.c]
2016-09-09 Reset GPS on startup
    [usart.c]
2016-09-09 Parse and print GPS GNTXT messages
2016-09-09 Parse GNGGA and print number of SV
2016-09-10 Print REPLIE signal
2016-09-12 Minor short beacon counter simplification
    [fsm.c]
2016-09-12 Reset short beacon counter on long beacon TX
    [fsm.c]
2016-09-12 Give name to codec reset pin
2016-09-15 Add debug for audio. Fix green blinking led
    [main.c]
2016-09-18 Remove TODO, schematic shows pin is never floating
2016-09-21 Update resistors on V1wire perfboard
2016-09-26 Add delays to fix aggressive FAULT_ADC1
    [analog_input.c, usart.c]
2016-09-26 Suspend scheduler while waiting for ADC measurement
2016-09-30 tm_mon is zero-indexed, unlike the month in GNRMC
    Fixes wrong DST correction, and likely problem we would have in December
    [main.c]
2016-12-20 Avoid letter delay if QSO duration was between 3 and 5 sec
    [fsm.c]
2017-04-30 Allow to open the relay with SQ using fax mode
2019-01-30 Update synoptique 2016 DB-25 connectors
2019-03-01 Add new FAX and 1750 interconnect board
2019-03-01 Remap PIOs in pio.txt, schematic and layout
2019-03-02 Allocate SQ2, DET 1750 and NF, partly adapt code, schematics and layout
2019-03-02 Default simulator voltage to 14V to stay in QRO
2019-04-11 Add some 1750 detection code to glutt-o-logic
    [af_5vpp_to_adc.sch, stm32f4discovery-with-stlinkv2.1.cfg]
2019-04-11 Switch debug UART to 115200
2019-04-11 Rework tone detector
    - Send buffer pointers from ISR to userspace
    - Use ADC interrupt to fetch data, not TIM6
    - Increase size of buffer and do double-buffering
    - Implement DTMF detectors
    - Compare relative results instead of using absolute thresholds
    - Add an IIR averaging filter on the results
    [audio_in.c, common.h, main.c]
2019-04-14 Add task cpu usage printout code, disabled by default
2019-04-14 Switch to 16kHz audio
2019-04-19 Fix FAX detection and output
    [audio_in.c, fsm.c, main.c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]
2019-05-03 Handle 1750 front button
2019-05-03 Minor schematic and board changes
2019-05-10 Modify orange LED usage
2019-05-10 Fix SQ2 output to 0
    [main.c]
2019-05-10 Move PA signal on fax_1750_interconnect schematic
2019-05-10 Fix tone LED in code and schematics
    [main.c, pio.c]
2019-06-19 Revert "Switch debug UART to 115200" and set it to 9600 again
    This reverts commit 7c7cd71c56808610be6af41dbeb09637026414bb.
    [usart.c]
2019-06-23 Show ALIM and TEMP independently of GPS time
    This avoids the bot complaining about no UART messages after a startup where GNSS never gets a fix
    [main.c]
2019-06-24 Add Kicad project for a NEO gps breakout board
    [gps.kicad_pcb, gps.sch]
2019-06-24 Modify QUCS sim for ADC input
    [af_5vpp_to_adc.sch]
2019-06-24 Fix wrong units and set hour_is_even for free-running clock mode
    [main.c]
2019-06-28 Fix FSM deadlock in FSM_BALISE_COURTE_OPEN
    When cw_psk31_done and sq occur simultaneously while inside FSM_BALISE_COURTE
    [fsm.c]
2019-07-01 Fix printf warnings
2019-07-05 Stats: add QSO duration, avoid calling build_text all the time
    [fsm.c, main.c]
2019-07-05 Adapt QRP QRO voltage thresholds
2019-07-09 Stats: fix uptime minutes and temperature
    [main.c]
2019-07-09 Stats: fix number of GNSS SVs used
    [main.c]
2019-12-07 Avoid using functions requiring locale support
    isdigit() and similar from ctype.h require this. Apparently
    this is not supported in the same way anymore on ARM.
2019-12-07 Fix statistics output of negative temperatures.
2020-04-20 Add BMP085 to the temperature sw project
2020-04-25 Add batterycharge to stats
2020-04-26 Enable STM32 USART2 RX
2020-08-11 Use battery charge to set QRP
2020-10-03 Add bat capacity in beacons
2020-10-03 Fix TEMP printout
2020-10-30 Handle batterycharge_wind_disconnected() returning -1
2020-10-30 Handle batterycharge_too_low() returning -1 properly
2020-11-16 FSM: Add temperature to QRP balise
2023-12-17 Keep temperature valid for 15 minutes
2024-12-26 Revert CW call sign back to HB9G
    This reverts commit f3dfdb91cbaeb150c6adf9461a1dc88ab4c0dc6e.
    [fsm.c]
